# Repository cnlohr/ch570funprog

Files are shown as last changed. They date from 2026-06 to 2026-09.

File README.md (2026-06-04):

# ch570funprog

Project Status: It works, in a pinch, but hardware and software is still evolving.

CH570-based programmer for CH32 microcontrollers.



### General Game Plan

- [x] Be a cheap, minichlink-compatible programmer programming over USB
- [x] Test on ch32v00x for SWIO mode (and tune)
- [ ] Test on more boards (And tune SWD)
- [ ] Be a iSLER gateway.
- [ ] Enable flashing of slave processors over iSLER.
- [ ] Enable self-program over iSLER

### Some Developer Notes

 * To force-enter SWD mode, hold D+ high.
 * You will need to `minichlink -P` to enable writing to the 570.

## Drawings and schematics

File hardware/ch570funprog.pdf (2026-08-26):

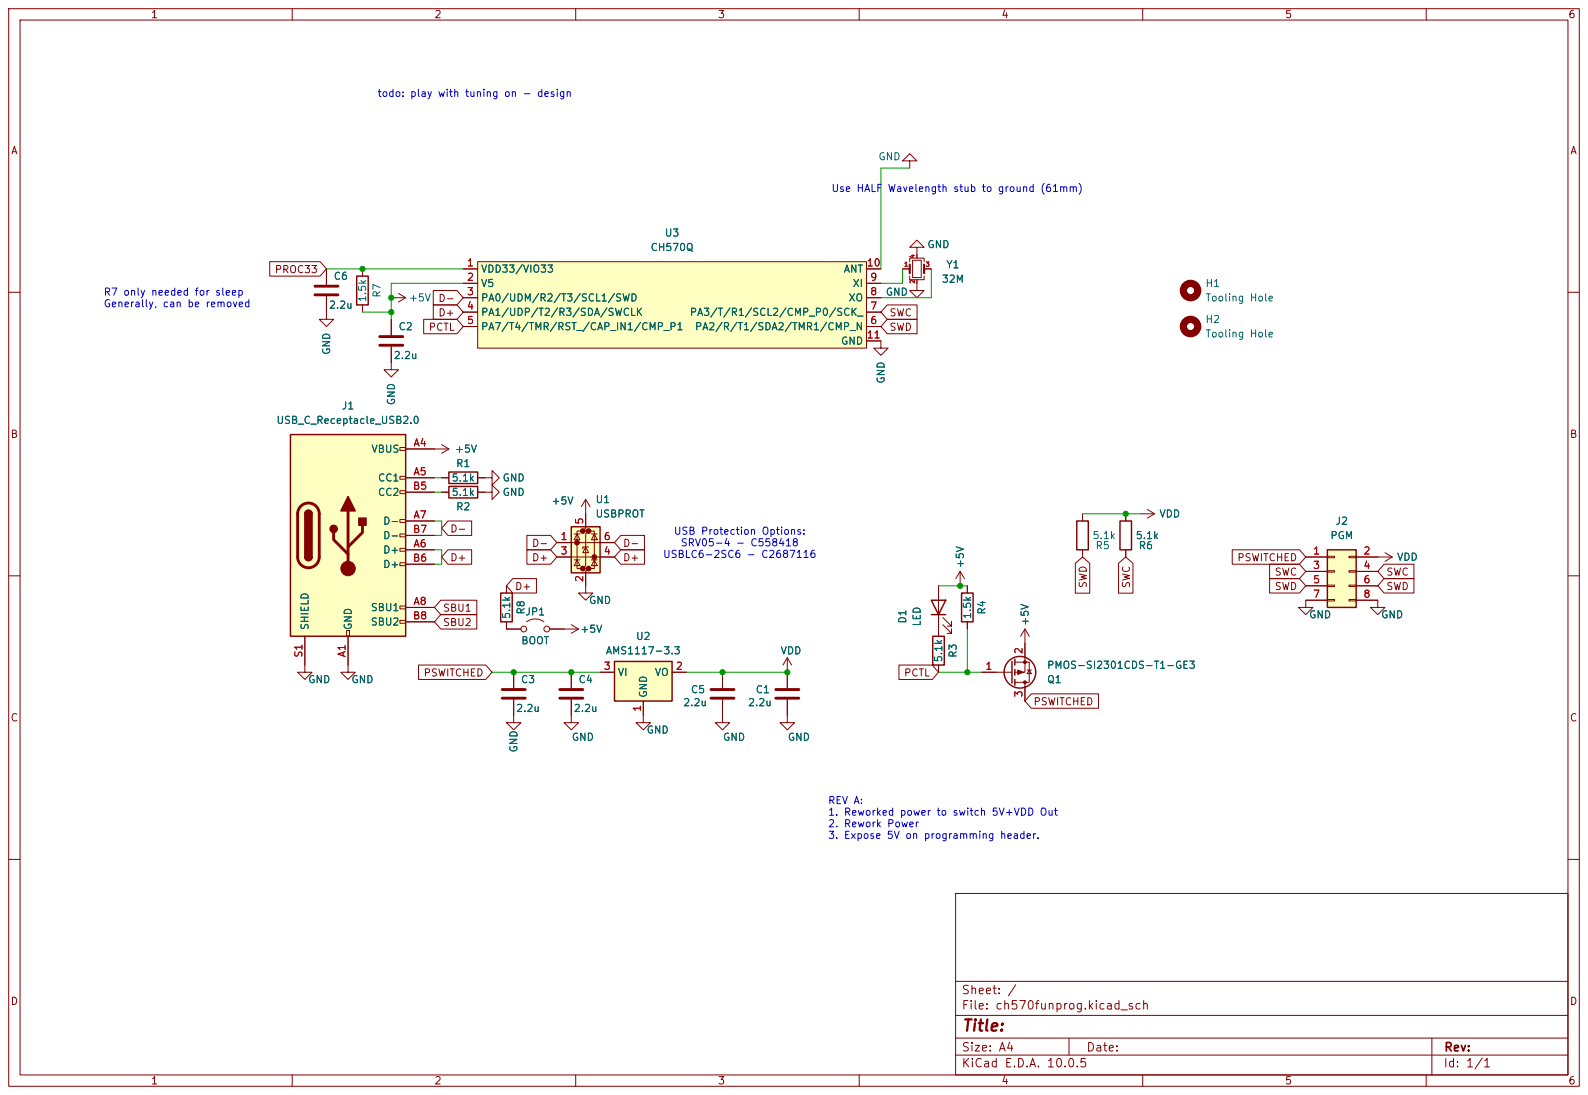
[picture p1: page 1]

todo: play with tuning on - design R7 only needed for sleep

REV A: 1. Reworked power to switch 5V+VDD Out 2. Rework Power 3. Expose 5V on programming header.

Size: A4 | Rev:
KiCad E.D.A. 10.0.5 | Id: 1/1

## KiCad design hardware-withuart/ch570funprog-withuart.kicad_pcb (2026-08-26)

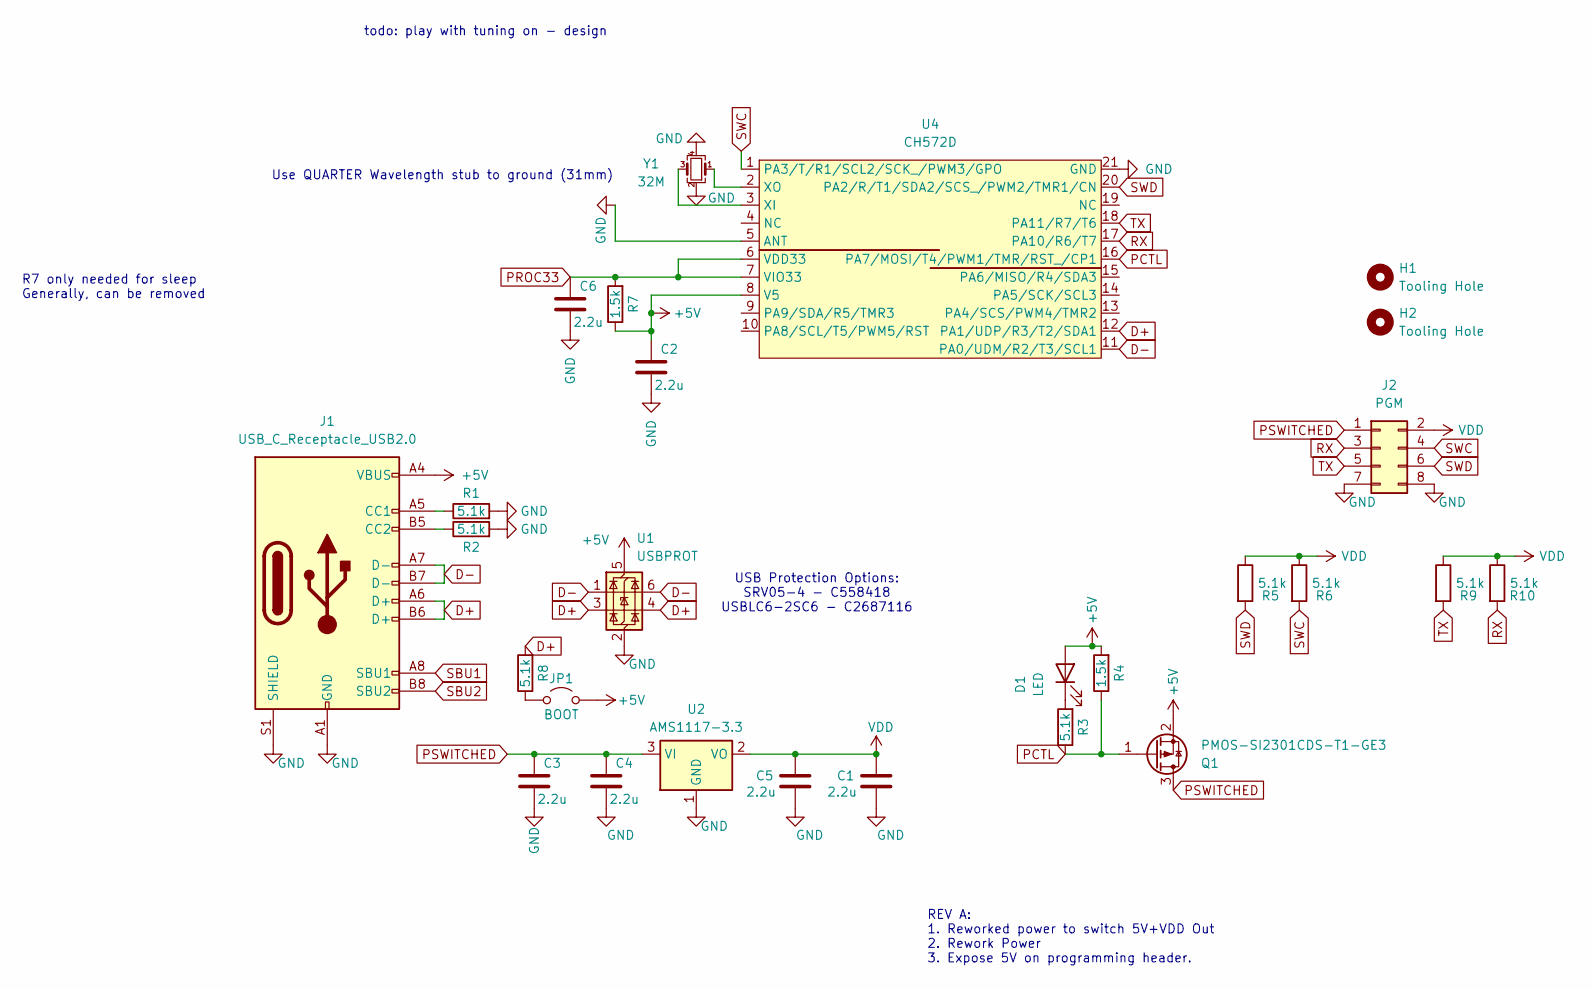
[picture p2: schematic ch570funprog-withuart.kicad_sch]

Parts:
C1, C2, C3, C4, C5, C6: 2.2u; R_0402_1005Metric; LCSC C12530
D1: LED; LED_0603_1608Metric; LCSC C2286
H1, H2: Tooling Hole; ToolingHole_JLCPCB
J1: USB_C_Receptacle_USB2.0; USB_C_MOD_Receptacle_HRO_TYPE-C-31-M-12; LCSC C2765186
J2: PGM; EDGE_02x04_2.54mm
JP1: BOOT; SolderJumper-2_P1.3mm_Open_TrianglePad1.0x1.5mm
Q1: PMOS-SI2301CDS-T1-GE3; SOT-23; LCSC C10487
R1, R2, R3, R5, R6, R8, R9, R10: 5.1k; R_0402_1005Metric; LCSC C25905
R4, R7: 1.5k; R_0402_1005Metric; LCSC C25867
U1: USBPROT; SOT-23-6; LCSC C558418
U2: AMS1117-3.3; SOT-223-3_TabPin2; LCSC C6186
U4: CH572D; QFN-20-1EP_3x3mm_P0.4mm_EP1.65x1.65mm; LCSC C46597863
Y1: 32M; Crystal_SMD_2016-4Pin_2.0x1.6mm; LCSC C718072

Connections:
+5V: C2.2, D1.2 (A), J1.A4 (VBUS), J1.A9 (VBUS), J1.B4 (VBUS), J1.B9 (VBUS), JP1.2 (B), Q1.2 (S), R4.2, R7.1, U1.5 (VBUS), U4.8 (V5)
D+: J1.A6 (D+), J1.B6 (D+), R8.2, U1.3 (I/O2), U1.4 (I/O2), U4.12 (PA1/UDP/R3/T2/SDA1)
D-: J1.A7 (D-), J1.B7 (D-), U1.1 (I/O1), U1.6 (I/O1), U4.11 (PA0/UDM/R2/T3/SCL1)
GND: C1.1, C2.1, C3.1, C4.1, C5.1, C6.1, J1.A1 (GND), J1.A12 (GND), J1.B1 (GND), J1.B12 (GND), J1.S1 (SHIELD), J2.7, J2.8, R1.2, R2.2, U1.2 (GND), U2.1 (GND), U4.5 (ANT), U4.21 (GND), Y1.2, Y1.4
unnamed: D1.1 (K), R3.2
unnamed: J1.A5 (CC1), R1.1
unnamed: J1.B5 (CC2), R2.1
unnamed: JP1.1 (A), R8.1
unnamed: U4.3 (XI), Y1.3
unnamed: U4.2 (XO), Y1.1
PCTL: Q1.1 (G), R3.1, R4.1, U4.16 (PA7/MOSI/T4/PWM1/TMR/RST_/CP1)
PROC33: C6.2, R7.2, U4.6 (VDD33), U4.7 (VIO33)
PSWITCHED: C3.2, C4.2, J2.1, Q1.3 (D), U2.3 (VI)
RX: J2.3, R10.2, U4.17 (PA10/R6/T7)
SBU1: J1.A8 (SBU1)
SBU2: J1.B8 (SBU2)
SWC: J2.4, R6.2, U4.1 (PA3/T/R1/SCL2/SCK_/PWM3/GPO)
SWD: J2.6, R5.2, U4.20 (PA2/R/T1/SDA2/SCS_/PWM2/TMR1/CN)
TX: J2.5, R9.2, U4.18 (PA11/R7/T6)
VDD: C1.2, C5.2, J2.2, R5.1, R6.1, R9.1, R10.1, U2.2 (VO)

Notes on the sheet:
REV A: 1. Reworked power to switch 5V+VDD Out 2. Rework Power 3. Expose 5V on programming header.
todo: play with tuning on - design
Use QUARTER Wavelength stub to ground (31mm)
USB Protection Options: SRV05-4 - C558418 USBLC6-2SC6 - C2687116
R7 only needed for sleep Generally, can be removed

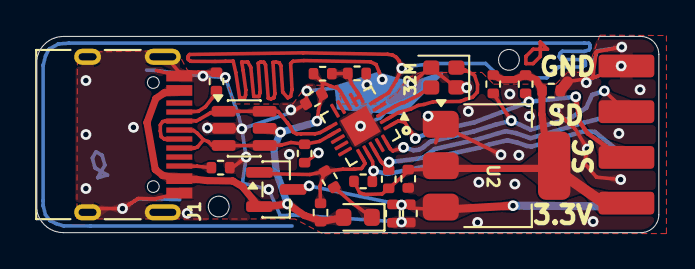
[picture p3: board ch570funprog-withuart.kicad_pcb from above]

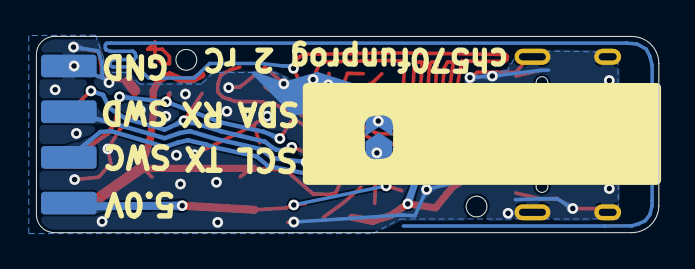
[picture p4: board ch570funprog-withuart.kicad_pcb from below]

Board: 2 copper layers, 34.6 x 10.9 mm, 27 parts (2 on the bottom side), 18 nets.

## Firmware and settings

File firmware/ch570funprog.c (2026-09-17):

#include "ch32fun.h"
#include <stdio.h>
#include <string.h>

#include "fsusb.h"


#define PIN_SWD PA2
#define PIN_SWC PA3

#define PIN_SWD_MASK (1<<2)
#define PIN_SWC_MASK (1<<3)

#define LED PA7
#define LED_ON 0
#define PIN_TARGETPOWER PA7

#define POWER_ON 0
#define POWER_OFF 1
#define PIN_TARGETPOWER_MODE GPIO_CFGLR_OUT_10Mhz_PP



// Allow reading and writing to the scratchpad via HID control messages.
__attribute__ ((aligned(4))) uint8_t scratch[511];
__attribute__ ((aligned(4))) uint8_t retbuff[511];

volatile uint32_t usb_pending = 0;
volatile uint32_t scratch_return = 0;

#include "the_programmer_from_ch32fun_rvswdio.h"

int doreboot = 0;
uint32_t rebootat = 0;

int didnak;

int missed, hit;

int HandleHidUserSetReportSetup( struct _USBState * ctx, tusb_control_request_t * req )
{
	int id = req->wValue & 0xff;
	if( ( id >= 0xaa && id <= 0xae ) && req->wLength <= sizeof(scratch) )
	{
		if( usb_pending ) return 0;
		ctx->pCtrlPayloadPtr = scratch;
		usb_pending = req->wLength;
		return req->wLength;
	}
	return 0;
}

int HandleHidUserGetReportSetup( struct _USBState * ctx, tusb_control_request_t * req )
{
	int id = req->wValue & 0xff;
	switch( id )
	{
	case 0xaa:
	case 0xab:
	case 0xac:
	case 0xad:
	case 0xae:
	{
		if( scratch_return )
		{
			hit++;
			scratch_return = 0;
			ctx->pCtrlPayloadPtr = retbuff;
			if( sizeof(retbuff) - 1 < req->wLength )
				return sizeof(retbuff) - 1;
			else
				return req->wLength;
		}
		else
		{
			missed++;
			didnak = req->wLength;
			return 0;
		}
	}
	case 0xe2: // Copy the printf debug buffer out of DMDATA0.
		memcpy( scratch, (char*)DMDATA0, 8 );
		ctx->pCtrlPayloadPtr = scratch;
		*DMDATA0 = 0;
		return 8;
	}
	return -1;
}

void HandleHidUserReportDataOut( struct _USBState * ctx, uint8_t * data, int len )
{
	switch( data[0] )
	{
	case 0xe1:
		if( len > 7 )
		{
			if( memcmp( (char*)(data+1), "\xbe\xef\x00\xc0\x01\xd0\x0d", 7 ) == 0 )
			{
				doreboot = 2;
				rebootat = SysTick->CNTL + 1000000;
			}
		}
		break;
	}
}

int HandleHidUserReportDataIn( struct _USBState * ctx, uint8_t * data, int len )
{
	memset( data, 0, len );
	return len;
}

void HandleHidUserReportOutComplete( struct _USBState * ctx )
{
	return;
}


__USBFS_FUN_ATTRIBUTE
static __attribute__((noreturn)) void processLoop()
{
	while(1)
	{
		//printf( "%lu %08lx %lu %d %d\n", USBDEBUG0, USBDEBUG1, USBDEBUG2, 0, 0 );
		if( doreboot )
		{
			if( (int)(SysTick->CNTL - rebootat) > 0 )
			{
#if defined(CH5xx)
				USBFSReset();
				jump_isprom();
#else
				// There aren't any other chips that can reboot into USB bootloader, are there?
#endif
			}
		}

/*
		struct SWIOState st;
		int r;
		r = InitializeSWDSWIO( &st );
		if( r == 0 )
		{
			uint8_t reply[8];
			r = DetermineChipTypeAndSectorInfo( &st, reply );
			printf( "Chip type: %d %02x %02x %02x %02x %02x %02x %02x %02x\n",
				r, reply[0], reply[1], reply[2], reply[3], reply[4], reply[5], reply[6], reply[7] );
			uint32_t esig = 0;
			r = ReadWord( &st, 0x1FFFF7E0, &esig );
			printf( "ESIG: %d %08x\n", r, (int)esig );
		}
		Delay_Ms(100);
*/


		if( usb_pending && !USBFSCTX.pCtrlPayloadPtr )
		{
			scratch_return = 0;
			//printf( "+%02x %02x %02x %02x %02x\n", scratch[0], scratch[1], scratch[2], scratch[3], scratch[4] );
			HandleCommandBuffer( scratch );
			//printf( "-%02x %02x %02x %02x %02x\n", scratch[0], scratch[1], scratch[2], scratch[3], scratch[4] );

			__disable_irq();
			if( didnak )
			{
				struct _USBState * ctx = &USBFSCTX;

				int len = didnak;

				if( sizeof(retbuff) - 1 < len )
					len = sizeof(retbuff) - 1;

				ctx->pCtrlPayloadPtr = retbuff;

				ctx->USBFS_SetupReqLen = len;
				len = len >= DEF_USBD_UEP0_SIZE ? DEF_USBD_UEP0_SIZE : len;

				uint8_t * ctrl0buff = CTRL0BUFF;
				memcpy( ctrl0buff, ctx->pCtrlPayloadPtr, len );
				ctx->pCtrlPayloadPtr += len;

				UEP_CTRL_LEN(0) = len;
				UEP_CTRL_TX(0) = CHECK_USBFS_UEP_T_AUTO_TOG | USBFS_UEP_T_RES_ACK | USBFS_UEP_T_TOG;
				ctx->USBFS_SetupReqLen -= len;

				didnak = 0;
			}
			__enable_irq();
			usb_pending = 0;
			scratch_return = 1;
		}

		_Static_assert( USB_EP_TX == 1 );
		// To service interrupt endpoint
		uint32_t * buffer = (uint32_t*)USBFS_GetEPBufferIfAvailable( USB_EP_TX );
		if( buffer )
		{
			buffer[0] = 0;
			buffer[1] = 0;
			USBFS_SendEndpoint( USB_EP_TX, 8 /* data length */ );
		}
	}
}



int main()
{
	SystemInit();

	funGpioInitAll();
	Delay_Ms(10);

	// Force reset.
	funDigitalWrite( LED, !LED_ON );
	funPinMode( LED, GPIO_CFGLR_OUT_10Mhz_PP );

	funDigitalWrite( PIN_SWD, 1 );
	funDigitalWrite( PIN_SWC, 1 );
	funPinMode( PIN_SWD, GPIO_CFGLR_OUT_10Mhz_PP );
	funPinMode( PIN_SWC, GPIO_CFGLR_OUT_10Mhz_PP );

//	printf("USBFS starting...");

	USBFSSetup();

//	printf("ok\n");

	funDigitalWrite( LED, LED_ON );

	processLoop();
}

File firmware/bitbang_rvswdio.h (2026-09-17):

// CH32V003 SWIO / CH32Vxxx / CH32Xxxx bit banging minimal reference
// implementation for bit banged IO or primitive IO.
//
// You will need to implement some of the basic functions. Example
// implementations for the functions on the ESP32-S2 are included.
//
// Copyright 2023-2024 <>< Charles Lohr, May be licensed under the MIT/x11 or
// NewBSD licenses. You choose. (Can be included in commercial and copyleft work)
//
// This file is original work.
//
// Mostly tested, though, not may not be perfect. Expect to tweak some things.
// The 003 code is pretty hardened, the other code may not be.
//
// Originally the only resources used to produce this file were publicly available docs
// and playing with the chips.  The only leveraged tool was this:
//   https://github.com/perigoso/sigrok-rvswd

#ifndef _WCH_RVSWD_RVSWIO_H
#define _WCH_RVSWD_RVSWIO_H

// This is a hacky thing, but if you are laaaaazzzyyyy and don't want to add a 10k
// resistor, youcan do this.  It glitches the line high very, very briefly.  
// Enable for when you don't have a 10k pull-upand are relying on the internal pull-up.
// WARNING: If you set this, you should set the drive current to 5mA.  This is 
// only useful / needed if you are using the built-in functions.
//#define R_GLITCH_HIGH
//#define RUNNING_ON_ESP32S2
//#define BB_PRINTF_DEBUG uprintf

// You should interface to this file via these functions

enum RiscVChip {
	CHIP_UNKNOWN = 0x00,
	CHIP_CH32V10x = 0x01,
	CHIP_CH57x = 0x02,
	CHIP_CH56x = 0x03,
	CHIP_CH32V20x = 0x05,
	CHIP_CH32V30x = 0x06,
	CHIP_CH58x = 0x07,
	CHIP_CH32V003 = 0x09,
	CHIP_CH59x = 0x0b,
	CHIP_CH643 = 0x0c,
	CHIP_CH32X03x = 0x0d,
	CHIP_CH32L10x = 0x0e,
	CHIP_CH564 = 0x0f,

	CHIP_CH32V00x = 0x4e,

	CHIP_CH570 = 0x8b,
	CHIP_CH585 = 0x4b,
	CHIP_CH645 = 0x46,
	CHIP_CH641 = 0x49,
	CHIP_CH32V317 = 0x86,
	CHIP_CH32M030 = 0x8e,
};

enum MemoryArea {
	DEFAULT_AREA = 0,
	PROGRAM_AREA = 1,
	BOOTLOADER_AREA = 2,
	OPTIONS_AREA = 3,
	EEPROM_AREA = 4,
	RAM_AREA = 5,
};

struct SWIOState
{
	// Set these before calling any functions
	int t1coeff;
	int pinmaskD;
	int pinmaskC;
	int opmode; // 0 for undefined, 1 for SWIO, 2 for SWD
	enum RiscVChip target_chip_type;
	int sectorsize;

	// Zero the rest of the structure.
	uint32_t statetag;
	uint32_t lastwriteflags;
	uint32_t currentstateval;
	uint32_t flash_unlocked;
	uint32_t autoincrement;
	uint32_t clock_set;
	uint32_t no_autoexec;
#if CH5xx_SUPPORT
	int microblob_running;
	int writing_flash;
#endif
};

#define STTAG( x ) (*((uint32_t*)(x)))

#define IRAM IRAM_ATTR

#ifdef RUNNING_ON_ESP32S2
// You may need to rewrite, depending on your architecture.
static inline void Send1BitSWIO( int t1coeff, int pinmaskD ) IRAM;
static inline void Send0BitSWIO( int t1coeff, int pinmaskD ) IRAM;
static inline int ReadBitSWIO( struct SWIOState * state ) IRAM;
static inline void SendBitRVSWD( int t1coeff, int pinmaskD, int pinmaskC, int val ) IRAM;
static inline int ReadBitRVSWD( int t1coeff, int pinmaskD, int pinmaskC ) IRAM;
#else
static inline void ConfigureIOForRVSWIO(void);
static inline void ConfigureIOForRVSWD(void);
#endif

// Provided Basic functions
void MCFWriteReg32( struct SWIOState * state, uint8_t command, uint32_t value ) IRAM;
int MCFReadReg32( struct SWIOState * state, uint8_t command, uint32_t * value ) IRAM;

// More advanced functions built on lower level PHY.
static int InitializeSWDSWIO( struct SWIOState * state );
#if CH5xx_SUPPORT
static int ReadByte( struct SWIOState * iss, uint32_t address_to_read, uint8_t * data );
static int WriteByte( struct SWIOState * iss, uint32_t address_to_write, uint8_t data );
#endif
static int ReadWord( struct SWIOState * state, uint32_t word, uint32_t * ret );
static int WriteWord( struct SWIOState * state, uint32_t word, uint32_t val );
static int WaitForFlash( struct SWIOState * state );
static int WaitForDoneOp( struct SWIOState * state );
static int WriteBlock( struct SWIOState * iss, uint32_t address_to_write, uint8_t * data, uint8_t len, uint8_t erase );
static int UnlockFlash( struct SWIOState * iss );
static int EraseFlash( struct SWIOState * iss, uint32_t address, uint32_t length, int type );
static void ResetInternalProgrammingState( struct SWIOState * iss );
static int PollTerminal( struct SWIOState * iss, uint8_t * buffer, int maxlen, uint32_t leavevalA, uint32_t leavevalB );

#if CH5xx_SUPPORT
extern int ch5xx_set_clock(struct SWIOState * iss, uint32_t clock);
extern int ch5xx_write_flash_using_microblob(struct SWIOState * iss, uint32_t start_addr, uint8_t* data, uint32_t len);
#endif

#define BDMDATA0        0x04
#define BDMDATA1        0x05
#define DMCONTROL      0x10
#define DMSTATUS       0x11
#define DMHARTINFO     0x12
#define DMABSTRACTCS   0x16
#define DMCOMMAND      0x17
#define DMABSTRACTAUTO 0x18
#define DMPROGBUF0     0x20
#define DMPROGBUF1     0x21
#define DMPROGBUF2     0x22
#define DMPROGBUF3     0x23
#define DMPROGBUF4     0x24
#define DMPROGBUF5     0x25
#define DMPROGBUF6     0x26
#define DMPROGBUF7     0x27

#define DMCPBR       0x7C
#define DMCFGR       0x7D
#define DMSHDWCFGR   0x7E

#ifndef __CH32V00x_H
#define FLASH_STATR_WRPRTERR       ((uint8_t)0x10) 
#define CR_PAGE_PG                 ((uint32_t)0x00010000)
#define CR_BUF_LOAD                ((uint32_t)0x00040000)
#ifndef FLASH_CTLR_MER
#define FLASH_CTLR_MER             ((uint16_t)0x0004)     /* Mass Erase */
#endif
#define CR_STRT_Set                ((uint32_t)0x00000040)
#define CR_PAGE_ER                 ((uint32_t)0x00020000)
#define CR_BUF_RST                 ((uint32_t)0x00080000)
#endif

#ifdef RUNNING_ON_ESP32S2

static inline void PrecDelay( int delay )
{
	asm volatile( 
"1: addi %[delay], %[delay], -1\n"
"   bbci %[delay], 31, 1b\n" : [delay]"+r"(delay)  );
}

// TODO: Add continuation (bypass) functions.
// TODO: Consider adding parity bit (though it seems rather useless)

// All three bit functions assume bus state will be in
// 	GPIO.out_w1ts = pinmask;
//	GPIO.enable_w1ts = pinmask;
// when they are called.
static inline void Send1BitSWIO( int t1coeff, int pinmaskD )
{
	// Low for a nominal period of time.
	// High for a nominal period of time.

	GPIO.out_w1tc = pinmaskD;
	PrecDelay( t1coeff );
	GPIO.out_w1ts = pinmaskD;
	PrecDelay( t1coeff );
}

static inline void Send0BitSWIO( int t1coeff, int pinmaskD )
{
	// Low for a LONG period of time.
	// High for a nominal period of time.
	int longwait = t1coeff*4;
	GPIO.out_w1tc = pinmaskD;
	PrecDelay( longwait );
	GPIO.out_w1ts = pinmaskD;
	PrecDelay( t1coeff );
}
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

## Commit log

2026-06-02 Updated readme + design
    [ch570funprog.kicad_pcb, ch570funprog.kicad_sch]
2026-06-03 Bump design and reorganize config location
    [ch570funprog.kicad_pcb, ch570funprog.kicad_sch]
2026-06-04 Update design
    [ch570funprog.kicad_pcb]
2026-07-12 Update to rev A
    [ch570funprog.kicad_pcb, ch570funprog.kicad_sch]
2026-07-12 Bump design
    [ch570funprog.kicad_pcb]
2026-07-14 Bump from re-order
    [ch570funprog.kicad_pcb]
2026-07-15 Prep for reupload with tooling holes
    [ch570funprog.kicad_pcb, ch570funprog.kicad_sch]
2026-07-29 Fix connectivity
    [ch570funprog.kicad_pcb, ch570funprog.kicad_sch]
2026-07-29 Fixup keepout
    [ch570funprog.kicad_pcb, ch570funprog.kicad_sch]
2026-08-25 Further tweaks, still trying to figure out bus reset issue.
    [ch570funprog.c]
2026-08-26 Add delay for boot Add ch570funprog with uart
    [ch570funprog-withuart.kicad_pcb, ch570funprog-withuart.kicad_sch]
2026-09-04 Work on debugging the no interrupt endpoint bug on my work machine
    [ch570funprog.c]
2026-10-24 Update undo italics on 570 board
2026-11-13 Add UART CDC. Add 100MHz option
2026-11-13 Extend trace a tiny amount
